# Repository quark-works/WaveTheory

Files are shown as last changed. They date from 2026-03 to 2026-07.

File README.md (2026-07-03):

# WaveTheroy

Wireless column staggered PCB compatible with GH60 tray mount cases.

<p align="center">
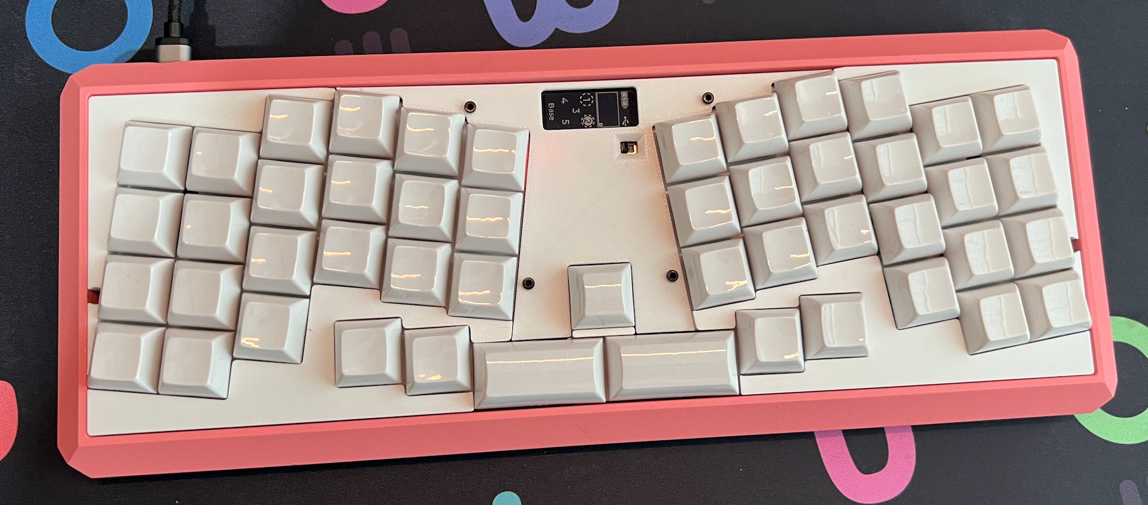
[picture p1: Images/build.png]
  
</p>

## Features
- 12x4 column staggered board with space for two optional encoders.
- Powered by a e73-2G4M08S1C module, nrf52840 and running ZMK. Firmware available here: [wavetheory-zmk-config](https://github.com/quark-works/wavetheroy-zmk-config).
- Board is in Full HV mode, with a battery of 110 mAh the expected life is around 1 month.
- Has space for a nice!view to show information regarding layers, battery, etc.
- Compatible with GH60 tray mount cases (as pictured).

## More pictures
<p align="center">
  
</p>

<p align="center">
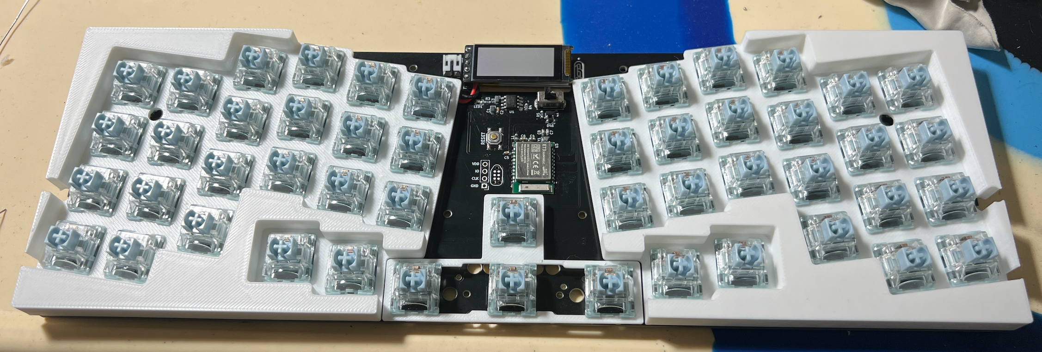
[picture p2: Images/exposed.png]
  
</p>

## This board was prototyped and working, but there are still things to do
- [ ] Add configuration in the firmware for the two encoders.
- [ ] Add configuration in the firmware for the missing compatible layouts.
- [ ] Provide a BOM and POS file for assembly.
- [ ] Fix a bodge wire in the prototype.

## Acknowledgements

Project based off from [Scientist Keyboard](https://github.com/godders/scientist). It uses the same layout based on their reference.

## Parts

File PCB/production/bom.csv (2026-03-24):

Designator | Footprint | Quantity | Value | LCSC Part #
C1, C3 | CP_EIA-2012-12_Kemet-R | 2 | 10uF
C2, C5, C6 | 0603 | 3 | 4.7u
C4 | 0603 | 1 | 1u
C7, C8 | 0603 | 2 | 12p
D1, D10, D11, D12, D13, D14, D15, D16, D17, D18, D19, D2, D20, D21, D22, D23, D24, D25, D26, D27, D28, D29, D3, D30, D31, D32, D33, D34, D35, D36, D37, D38, D39, D4, D40, D41, D42, D43, D44, D45, D47, D48, D49, D5, D50, D51, D6, D7, D8, D9 | CUSTOM D_SOD-123 | 50 | 1N4148
D46 | 0603 | 1 | Schottky
DISPLAY1 | nice_view | 1 | nice!view
F1 | 1206 | 1 | 500 mA
J2 | USB_C_Receptacle_HRO_TYPE-C-31-M-12 | 1 | USB_C_Receptacle_USB2.0
J3 | JST_PH_S2B-PH-K_1x02_P2.00mm_Horizontal | 1 | Battery | C505023
L1 | 0603 | 1 | 10 uH | C92982
LED1 | 0805 | 1 | CHARGE
MX1, MX10, MX11, MX12, MX13, MX14, MX15, MX16, MX17, MX18, MX19, MX2, MX20, MX21, MX22, MX23, MX24, MX25, MX26, MX27, MX28, MX29, MX3, MX30, MX31, MX32, MX33, MX34, MX35, MX36, MX37, MX38, MX39, MX4, MX40, MX41, MX42, MX43, MX44, MX45, MX46, MX47, MX48, MX49, MX5, MX50, MX52, MX53, MX6, MX7, MX8, MX9 | SW_MX_1u | 52 | MX_SW_HS
Q1 | SOT-23 | 1 | AO3401A
R1, R2 | 0603 | 2 | 5.1k
R3 | 0603 | 1 | 10k
R4, R5 | 0603 | 2 | 5k
R6 | 0603 | 1 | 1M
S1, S2, S3 | STAB_MX_P_2u | 3 | MX_stab
SW1 | SW_Slide_SPDT_Straight_CK_OS102011MS2Q | 1 | SW_SPDT | C41430893
SW2 | SW_SPST_SKQG_WithStem | 1 | SW_Push
SW3, SW4, SW5 | ROT_Alps_EC11E-Switch | 3 | RotaryEncoder_Switch_MP
U1 | CustomTP4056 | 1 | TP4056 | C16581
U2 | SOT-23-6 | 1 | USBLC6-2SC6
U3 | nRF52840_E73-2G4M08S1C | 1 | nRF52840_E73-2G4M08S1C | C356849
Y1 | Crystal_SMD_2012-2Pin_2.0x1.2mm | 1 | 32.768 KHz | C55208

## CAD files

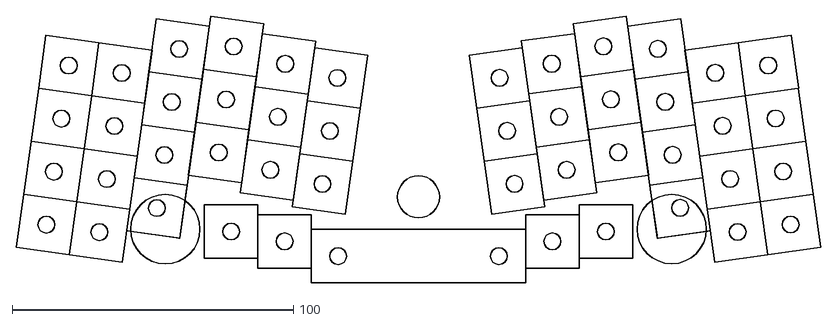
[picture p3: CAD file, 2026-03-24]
PCB/Reference/scientist-layout.dxf
286.3 x 94.9

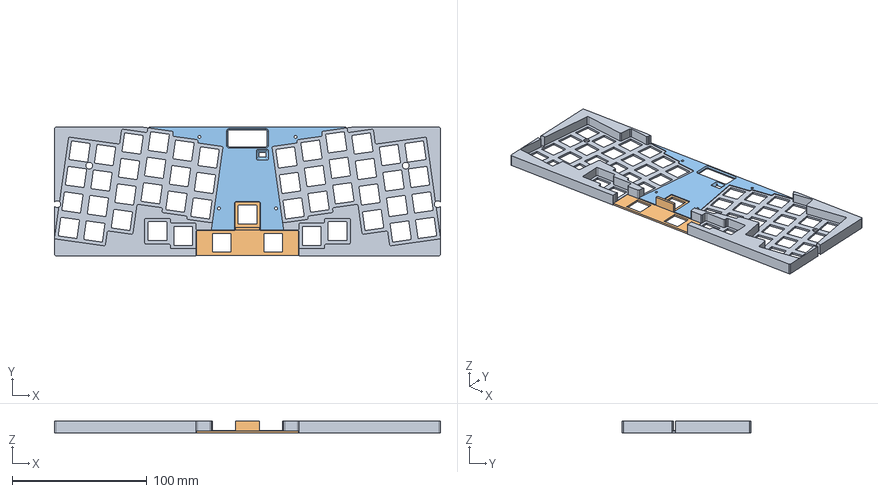
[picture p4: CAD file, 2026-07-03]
Plate/WaveTheoryPlate.step
286.0 x 95.2 x 9.00 mm

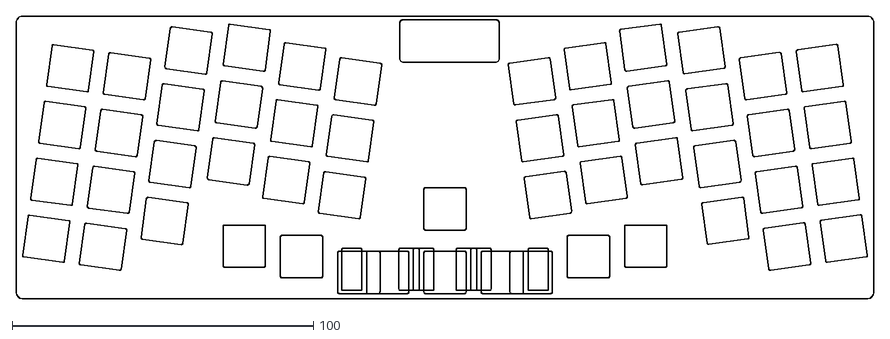
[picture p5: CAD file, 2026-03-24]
PCB/Reference/WaveTheory-User_Eco2.dxf
284.7 x 93.7

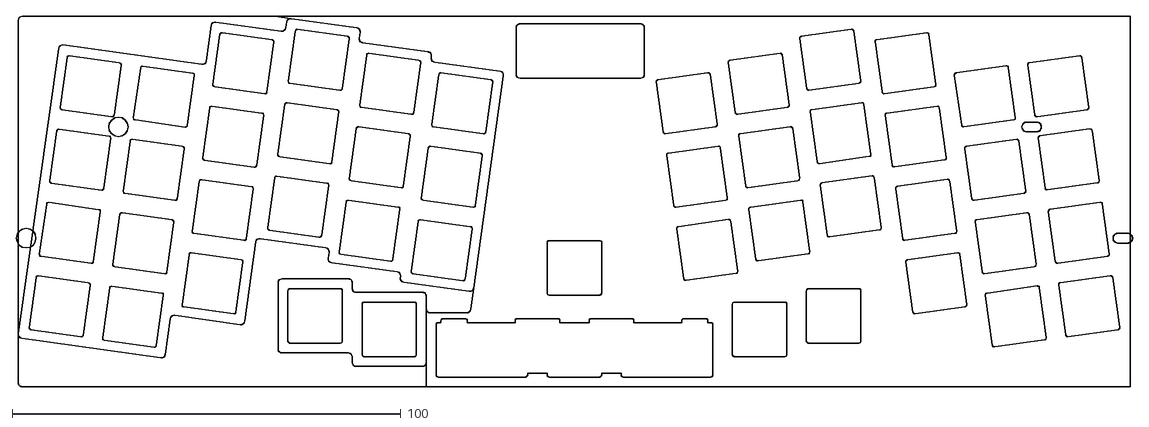
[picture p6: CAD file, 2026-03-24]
PCB/Reference/WaveTheoryPlate.dxf
287.0 x 95.2

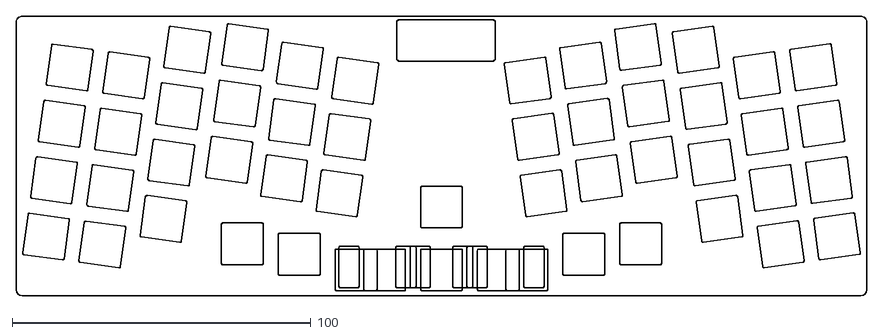
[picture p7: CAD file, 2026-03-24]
PCB/Reference/WaveTheory-Edge_Cuts.dxf
284.7 x 93.7

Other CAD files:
PCB/Reference/scientist-layout.dwg

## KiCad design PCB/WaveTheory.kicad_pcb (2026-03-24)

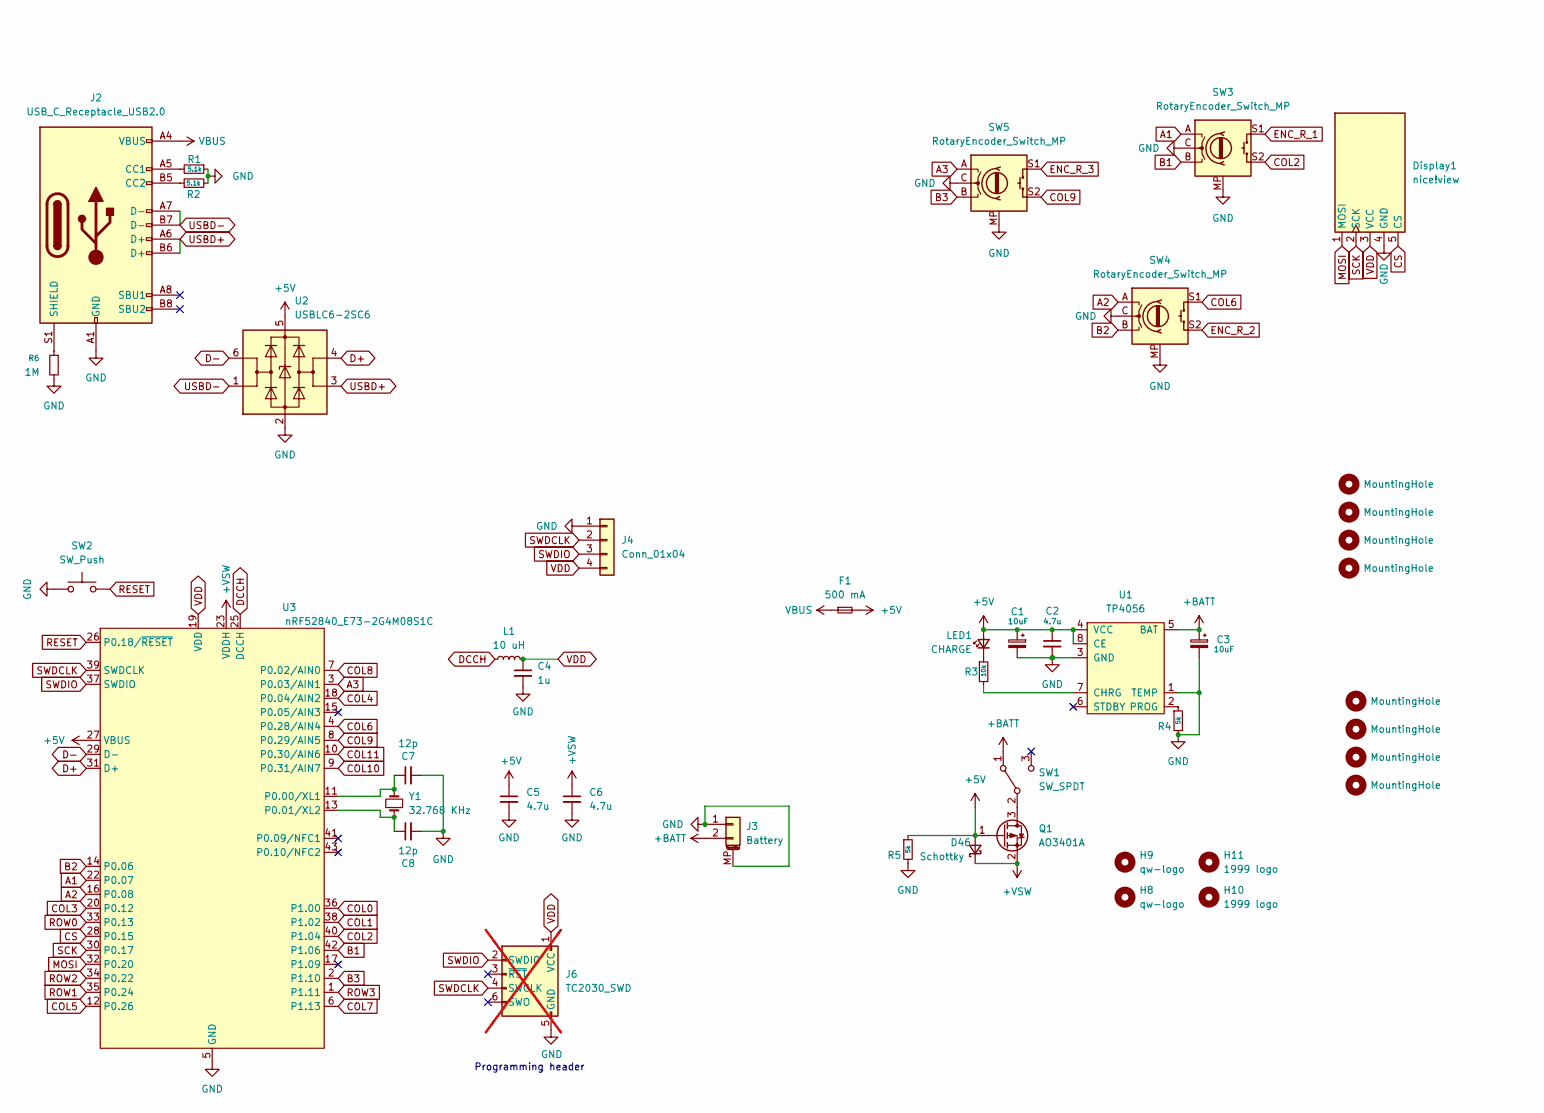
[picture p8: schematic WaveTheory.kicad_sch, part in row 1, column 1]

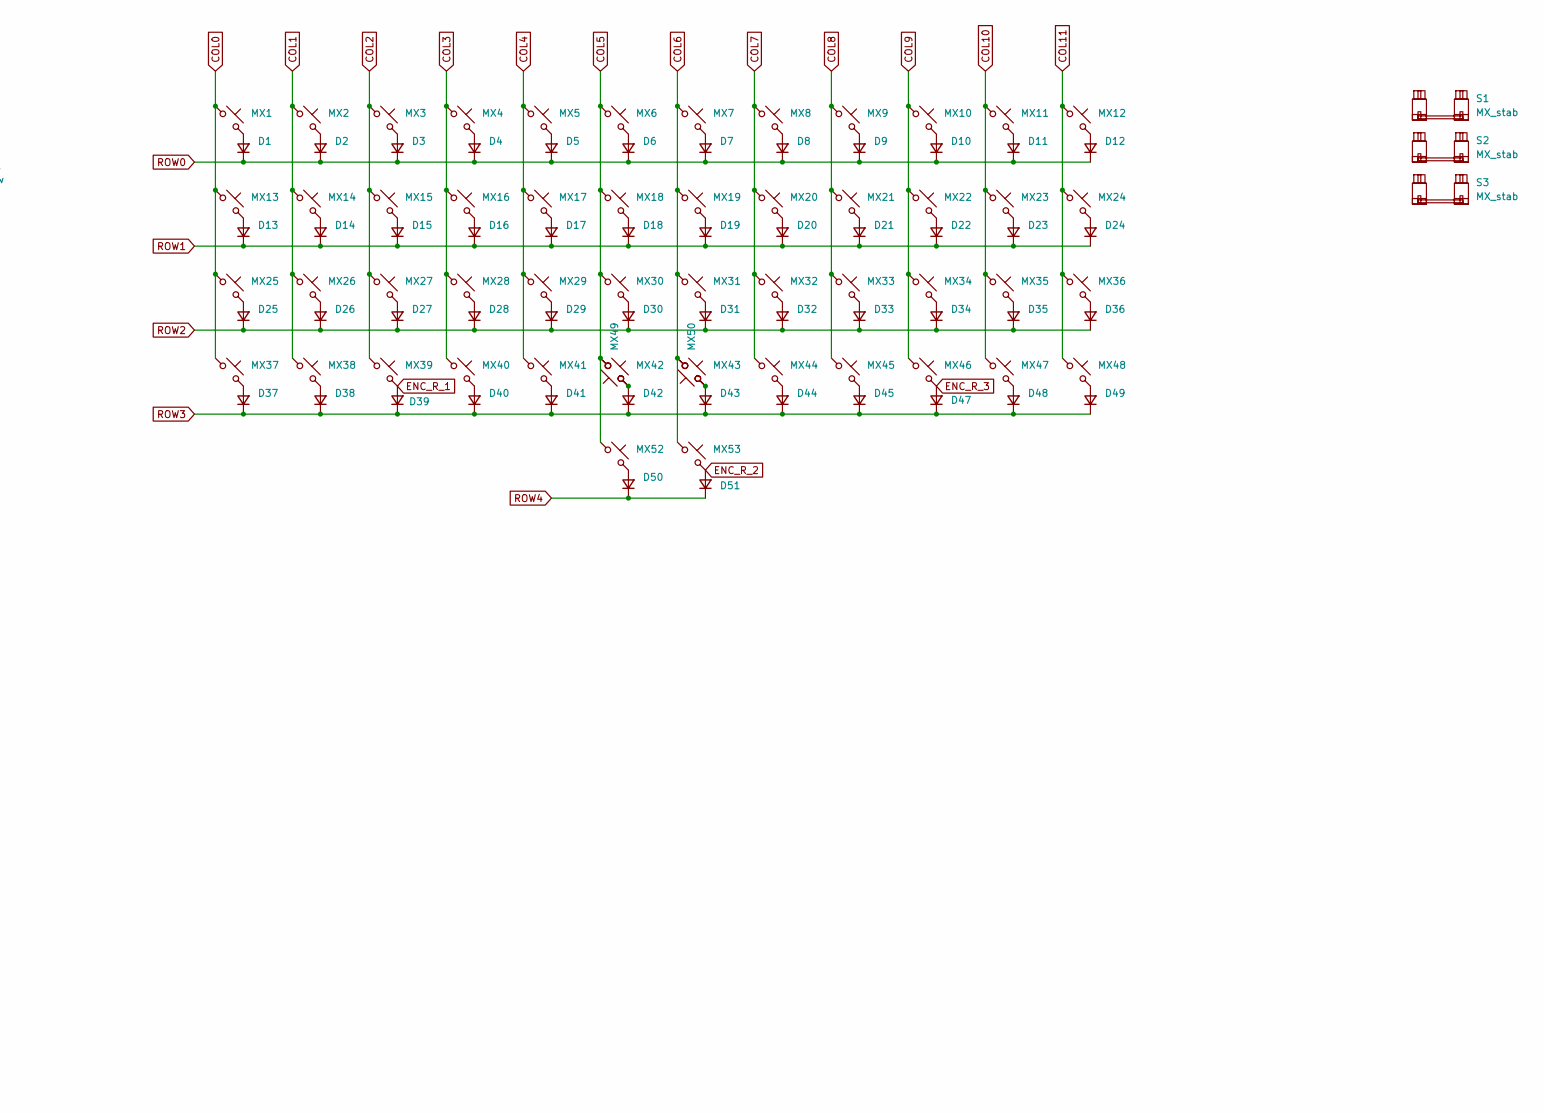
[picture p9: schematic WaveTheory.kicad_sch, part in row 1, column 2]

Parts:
C1, C3: 10uF; CP_EIA-2012-12_Kemet-R
C2, C5, C6: 4.7u; C_0603_1608Metric
C4: 1u; C_0603_1608Metric
C7, C8: 12p; C_0603_1608Metric
D1, D2, D3, D4, D5, D6, D7, D8, D9, D10, D11, D12, D13, D14, D15, D16, D17, D18, D19, D20, D21, D22, D23, D24, D25, D26, D27, D28, D29, D30, D31, D32, D33, D34, D35, D36, D37, D38, D39, D40, D41, D42, D43, D44, D45, D47, D48, D49, D50, D51: 1N4148; CUSTOM D_SOD-123
D46: Schottky; D_0603_1608Metric
Display1: nice!view; nice_view
F1: 500 mA; Fuse_1206_3216Metric
H1, H2, H3, H4: MountingHole; mounting_hole
H5, H6, H7, H12: MountingHole; MountingHole_2.2mm_M2
H8, H9: qw-logo; qw new logo silk + copper sm
H10, H11: 1999 logo; 1999 logo md
J2: USB_C_Receptacle_USB2.0; USB_C_Receptacle_HRO_TYPE-C-31-M-12
J3: Battery; JST_PH_S2B-PH-K_1x02_P2.00mm_Horizontal; LCSC C505023
J4: Conn_01x04; PinHeader_1x04_P2.54mm_Vertical
J6: TC2030_SWD; CON_TC2030_outlined; not fitted
L1: 10 uH; L_0603_1608Metric; LCSC C92982
LED1: CHARGE; LED_0805_2012Metric
MX1, MX2, MX3, MX4, MX5, MX6, MX7, MX8, MX9, MX10, MX11, MX12, MX13, MX14, MX15, MX16, MX17, MX18, MX19, MX20, MX21, MX22, MX23, MX24, MX25, MX26, MX27, MX28, MX29, MX30, MX31, MX32, MX33, MX34, MX35, MX36, MX37, MX38, MX39, MX40, MX41, MX42, MX43, MX44, MX45, MX46, MX47, MX48, MX49, MX50, MX52, MX53: MX_SW_HS; SW_MX_1u
Q1: AO3401A; SOT-23
R1, R2: 5.1k; R_0603_1608Metric
R3: 10k; R_0603_1608Metric
R4, R5: 5k; R_0603_1608Metric
R6: 1M; R_0603_1608Metric
S1, S2, S3: MX_stab; STAB_MX_P_2u
SW1: SW_SPDT; SW_Slide_SPDT_Straight_CK_OS102011MS2Q; LCSC C41430893
SW2: SW_Push; SW_SPST_SKQG_WithStem
SW3, SW4, SW5: RotaryEncoder_Switch_MP; ROT_Alps_EC11E-Switch
U1: TP4056; CustomTP4056; LCSC C16581
U2: USBLC6-2SC6; SOT-23-6
U3: nRF52840_E73-2G4M08S1C; LCSC C356849
Y1: 32.768 KHz; Crystal_SMD_2012-2Pin_2.0x1.2mm; LCSC C55208

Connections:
+5V: C1.1, C2.1, C5.1, D46.2 (A), F1.2, LED1.2 (A), Q1.1 (G), R5.1, U1.4 (VCC), U1.8 (CE), U2.5 (VBUS), U3.27 (VBUS)
+BATT: C3.1, J3.2, SW1.1 (A), U1.5 (BAT)
+VSW: C6.1, D46.1 (K), Q1.2 (S), U3.23 (VDDH)
A1: SW3.A, U3.22 (P0.07)
A2: SW4.A, U3.16 (P0.08)
A3: SW5.A, U3.3 (P0.03/AIN1)
B1: SW3.B, U3.42 (P1.06)
B2: SW4.B, U3.14 (P0.06)
B3: SW5.B, U3.2 (P1.10)
COL0: MX1.2, MX13.2, MX25.2, MX37.2, U3.36 (P1.00)
COL1: MX2.2, MX14.2, MX26.2, MX38.2, U3.38 (P1.02)
COL2: MX3.2, MX15.2, MX27.2, MX39.2, SW3.S2, U3.40 (P1.04)
COL3: MX4.2, MX16.2, MX28.2, MX40.2, U3.20 (P0.12)
COL4: MX5.2, MX17.2, MX29.2, MX41.2, U3.18 (P0.04/AIN2)
COL5: MX6.2, MX18.2, MX30.2, MX42.2, MX49.2, MX52.2, U3.12 (P0.26)
COL6: MX7.2, MX19.2, MX31.2, MX43.2, MX50.2, MX53.2, SW4.S1, U3.4 (P0.28/AIN4)
COL7: MX8.2, MX20.2, MX32.2, MX44.2, U3.6 (P1.13)
COL8: MX9.2, MX21.2, MX33.2, MX45.2, U3.7 (P0.02/AIN0)
COL9: MX10.2, MX22.2, MX34.2, MX46.2, SW5.S2, U3.8 (P0.29/AIN5)
COL10: MX11.2, MX23.2, MX35.2, MX47.2, U3.9 (P0.31/AIN7)
COL11: MX12.2, MX24.2, MX36.2, MX48.2, U3.10 (P0.30/AIN6)
CS: Display1.5 (CS), U3.28 (P0.15)
D+: U2.4 (I/O2), U3.31 (D+)
D-: U2.6 (I/O1), U3.29 (D-)
DCCH: L1.1, U3.25 (DCCH)
ENC_R_1: D39.2 (A), MX39.1, SW3.S1
ENC_R_2: D51.2 (A), MX53.1, SW4.S2
ENC_R_3: D47.2 (A), MX46.1, SW5.S1
GND: C1.2, C2.2, C3.2, C4.2, C5.2, C6.2, C7.2, C8.2, Display1.4 (GND), J2.A1 (GND), J2.A12 (GND), J2.B1 (GND), J2.B12 (GND), J3.1, J3.MP (MountPin), J4.1, J6.5 (GND), R1.1, R2.2, R4.2, R5.2, R6.2, SW2.1, SW3.C, SW3.MP, SW4.C, SW4.MP, SW5.C, SW5.MP, U1.1 (TEMP), U1.3 (GND), U2.2 (GND), U3.5 (GND), U3.21 (GND), U3.24 (GND)
MOSI: Display1.1 (MOSI), U3.32 (P0.20)
unnamed: D1.2 (A), MX1.1
unnamed: D2.2 (A), MX2.1
unnamed: D3.2 (A), MX3.1
unnamed: D4.2 (A), MX4.1
unnamed: D5.2 (A), MX5.1
unnamed: D6.2 (A), MX6.1
unnamed: D7.2 (A), MX7.1
unnamed: D8.2 (A), MX8.1
unnamed: D9.2 (A), MX9.1
unnamed: D10.2 (A), MX10.1
unnamed: D11.2 (A), MX11.1
unnamed: D12.2 (A), MX12.1
unnamed: D13.2 (A), MX13.1
unnamed: D14.2 (A), MX14.1
unnamed: D15.2 (A), MX15.1
unnamed: D16.2 (A), MX16.1
unnamed: D17.2 (A), MX17.1
unnamed: D18.2 (A), MX18.1
unnamed: D19.2 (A), MX19.1
unnamed: D20.2 (A), MX20.1
unnamed: D21.2 (A), MX21.1
unnamed: D22.2 (A), MX22.1
unnamed: D23.2 (A), MX23.1
unnamed: D24.2 (A), MX24.1
unnamed: D25.2 (A), MX25.1
unnamed: D26.2 (A), MX26.1
unnamed: D27.2 (A), MX27.1
unnamed: D28.2 (A), MX28.1
unnamed: D29.2 (A), MX29.1
unnamed: D30.2 (A), MX30.1
unnamed: D31.2 (A), MX31.1
unnamed: D32.2 (A), MX32.1
unnamed: D33.2 (A), MX33.1
unnamed: D34.2 (A), MX34.1
unnamed: D35.2 (A), MX35.1
unnamed: D36.2 (A), MX36.1
unnamed: D37.2 (A), MX37.1
unnamed: D38.2 (A), MX38.1
unnamed: D40.2 (A), MX40.1
unnamed: D41.2 (A), MX41.1
unnamed: D42.2 (A), MX42.1, MX49.1
unnamed: D43.2 (A), MX43.1, MX50.1
unnamed: D44.2 (A), MX44.1
unnamed: D45.2 (A), MX45.1
unnamed: D48.2 (A), MX47.1
unnamed: D49.2 (A), MX48.1
unnamed: D50.2 (A), MX52.1
unnamed: J2.A5 (CC1), R1.2
unnamed: J2.B5 (CC2), R2.1
unnamed: J2.S1 (SHIELD), R6.1
unnamed: LED1.1 (K), R3.1
unnamed: Q1.3 (D), SW1.2 (B)
unnamed: R3.2, U1.7 (CHRG)
unnamed: R4.1, U1.2 (PROG)
unnamed: C7.1, U3.11 (P0.00/XL1), Y1.2
unnamed: C8.1, U3.13 (P0.01/XL2), Y1.1
RESET: SW2.2, U3.26 (P0.18/~RESET)
ROW0: D1.1 (K), D2.1 (K), D3.1 (K), D4.1 (K), D5.1 (K), D6.1 (K), D7.1 (K), D8.1 (K), D9.1 (K), D10.1 (K), D11.1 (K), D12.1 (K), U3.33 (P0.13)
ROW1: D13.1 (K), D14.1 (K), D15.1 (K), D16.1 (K), D17.1 (K), D18.1 (K), D19.1 (K), D20.1 (K), D21.1 (K), D22.1 (K), D23.1 (K), D24.1 (K), U3.35 (P0.24)
ROW2: D25.1 (K), D26.1 (K), D27.1 (K), D28.1 (K), D29.1 (K), D30.1 (K), D31.1 (K), D32.1 (K), D33.1 (K), D34.1 (K), D35.1 (K), D36.1 (K), U3.34 (P0.22)
ROW3: D37.1 (K), D38.1 (K), D39.1 (K), D40.1 (K), D41.1 (K), D42.1 (K), D43.1 (K), D44.1 (K), D45.1 (K), D47.1 (K), D48.1 (K), D49.1 (K), U3.1 (P1.11)
ROW4: D50.1 (K), D51.1 (K)
SCK: Display1.2 (SCK), U3.30 (P0.17)
SWDCLK: J4.2, J6.4 (SWCLK), U3.39 (SWDCLK)
SWDIO: J4.3, J6.2 (SWDIO), U3.37 (SWDIO)
USBD+: J2.A6 (D+), J2.B6 (D+), U2.3 (I/O2)
USBD-: J2.A7 (D-), J2.B7 (D-), U2.1 (I/O1)
VBUS: F1.1, J2.A4 (VBUS), J2.A9 (VBUS), J2.B4 (VBUS), J2.B9 (VBUS)
VDD: C4.1, Display1.3 (VCC), J4.4, J6.1 (VCC), L1.2, U3.19 (VDD)

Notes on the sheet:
Programming header

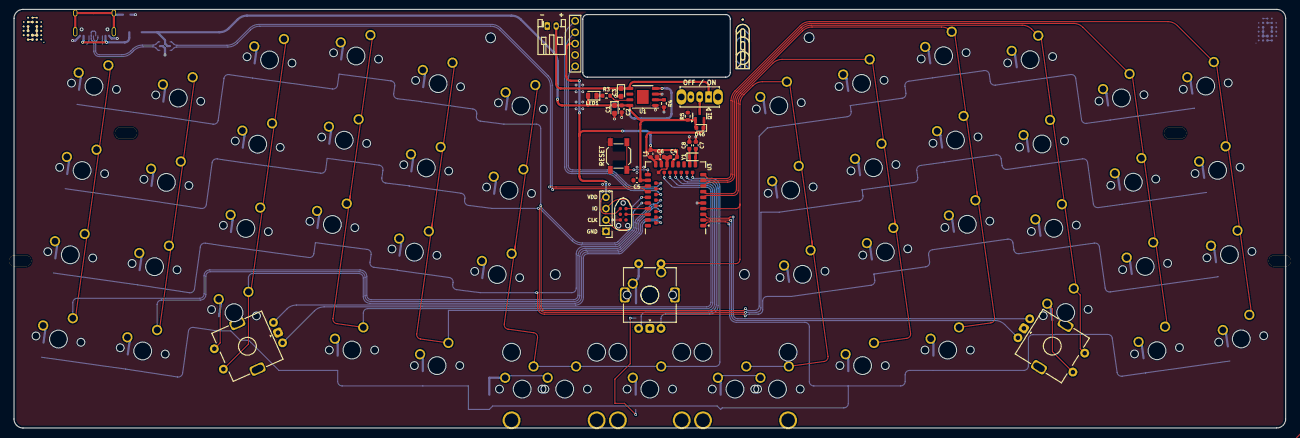
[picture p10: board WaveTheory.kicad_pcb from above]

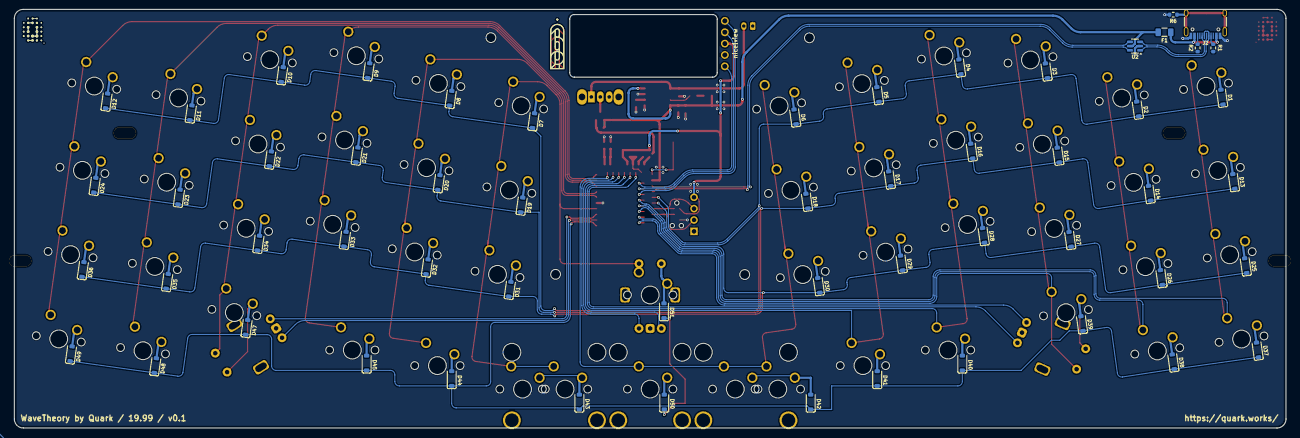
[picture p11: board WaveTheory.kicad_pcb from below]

Board: 2 copper layers, 284.6 x 93.7 mm, 150 parts (58 on the bottom side), 99 nets.

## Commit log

2025-12-23 First commit!
    [WaveTheory.kicad_pcb, WaveTheory.kicad_sch]
2026-03-24 First revision
    [WaveTheory-Edge_Cuts.dxf, WaveTheory-User_Eco2.dxf, WaveTheory.kicad_pcb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]
2026-03-24 added original reference
    [scientist-layout.dwg, scientist-layout.dxf]
